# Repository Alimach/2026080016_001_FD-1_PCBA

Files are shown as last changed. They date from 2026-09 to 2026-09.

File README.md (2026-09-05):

# 2026080016_001_FD-1_PCBA

Проект печатной платы гитарной педали "First Distortion FD-1".

ID проекта: 2026080016.001

© Александр Алимов, 2026

---

## Лицензия

Данный проект распространяется под лицензией **Creative Commons CC-BY-NC 4.0**, 
согласно которой вы можете свободно делиться материалом и адаптировать его под 
свои нужды, при условии указания авторства и некоммерческого использования 
(подробнее см. файл LICENSE).

## Описание проекта

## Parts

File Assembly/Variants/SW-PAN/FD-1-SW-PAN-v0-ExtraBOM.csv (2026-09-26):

Name | Value | Qty | Unit | Описание | Type | MPN | Manufacturer | Chipdip_link | Diy-tubes_link | Diy-tubes_alt_link
Плата печатная 2026080016.001 FD-1 v0 |  | 1 | pcs |  | Detail | PCB-2026080016-001-FD-1-v0
Лепесток 1-2-13-36 |  | 1 | pcs | Для подключения GND к корпусу | Other
Провод МГШВ-0,2 кв.мм (AWG24), белый | 0,2 кв.мм (AWG24), белый | 100 | mm |  | Material
Провод МГШВ-0,2 кв.мм (AWG24), красный | 0,2 кв.мм (AWG24), красный | 50 | mm |  | Material
Провод МГШВ-0,2 кв.мм (AWG24), черный | 0,2 кв.мм (AWG24), черный | 100 | mm |  | Material
Трубка ПВХ Ø 1 мм | Ø 1 мм |  | mm |  | Material
Вилка штыревая PLH-5 | PLH-5 | 1 | pcs |  | Other

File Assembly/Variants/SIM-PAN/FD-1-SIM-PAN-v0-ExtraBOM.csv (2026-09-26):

Name | Value | Qty | Описание | MPN | Manufacturer | Chipdip_link | Diy-tubes_link | Diy-tubes_alt_link
Плата печатная 2026080016.001 FD-1 v0 |  | 1 |  | PCB-2026080016-001-FD-1-v0
Провод МГШВ-0.2 кв.мм (AWG24) | 0.2 кв.мм (AWG24)
Лепесток 1-2-13-36 |  | 1 | Для подключения GND к корпусу

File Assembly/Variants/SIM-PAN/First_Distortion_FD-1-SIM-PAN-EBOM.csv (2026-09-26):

Reference | Name | Value | Tolerance | Voltage | Power | Temperature | Material | Package | PinPitch | Qty | Описание | MPN | Manufacturer | Chipdip_link | Diy-tubes_link | Diy-tubes_alt_link
C1,C9 | Конденсатор THT металлоплёночный | 1n | 20% | 63V |  |  | MKT | C-THT-RECT-L7-W2.5-H6.5 | 5 | 2 |  | B32529C0102 | Epcos | https://www.chipdip.ru/product/b32529c0102j000-0.001-mkf-40vac-63vdc-shag-5mm-5-tdk-epcos-9000635053 | https://diy-tubes.ru/index.php?route=product/product&path=25_32&product_id=912 | https://diy-tubes.ru/index.php?route=product/product&path=25_32&product_id=560
C2 | Конденсатор THT металлоплёночный | 10n | 20% | 63V |  |  | MKT | C-THT-RECT-L7-W2.5-H6.5 | 5 | 1 |  | B32529C0103 | Epcos | https://www.chipdip.ru/product/b32529c0103j000-tdk-8008394032 | https://diy-tubes.ru/index.php?route=product/product&path=25_32&product_id=912 | https://diy-tubes.ru/index.php?route=product/product&path=25_32&product_id=560
C3 | Конденсатор THT металлоплёночный | 47n | 20% | 63V |  |  | MKT | C-THT-RECT-L7-W2.5-H6.5 | 5 | 1 |  | B32529C0473 | Epcos | https://www.chipdip.ru/product/mkt-film-capacitor-47-nf-10-63-v-dc-pet-5-mm-tdk-8026536943 | https://diy-tubes.ru/index.php?route=product/product&path=25_32&product_id=912 | https://diy-tubes.ru/index.php?route=product/product&path=25_32&product_id=560
C4 | Конденсатор THT электролитический алюминиевый | 100u | 20% | 16V |  | 85 °C | AL-EL | C-THT-RADIAL-D5-H11 | 2.5 | 1 |  | JRB1C101M02000500110 | JB | https://www.chipdip.ru/product/100mkf-16v-105-c-20-5x11mm-p-2mm-jb-capacitors-9000565888
C5 | Конденсатор THT керамический | 10p | 5% | 50V |  |  | NP0 | C-THT-RECT-L5-W2.5-H5 | 5 | 1 |  | JYM1H100JBN | JB | https://www.chipdip.ru/product/k10-17b-10pf-npo-5-0805-jym1h100jbn010000b-jb-capacitors-9001397195 |  | https://diy-tubes.ru/index.php?route=product/product&path=25_32&product_id=937
C6 | Конденсатор THT электролитический танталовый | 1u | 10% | 50V |  |  | TA-EL | C-THT-RADIAL-D5-H11 | 2.5 | 1 | Танталовый, ниобиевый | TC-1/50 | SR Passives | https://www.chipdip.ru/product/tc-1-50-kondensator-tantalovyy-1mkf-50v-tht-20-sr-passives-8017379192
C7 | Конденсатор THT электролитический алюминиевый | 1u | 20% | 50V |  | 85 °C | AL-EL | C-THT-RADIAL-D5-H11 | 2.5 | 1 |  | JRB1H010M02000500110 | JB | https://www.chipdip.ru/product/1mkf-50v-105-c-20-5x11mm-p-2mm-jb-capacitors-9000565817 |  | https://diy-tubes.ru/index.php?route=product/product&path=25_32&product_id=330
C8 | Конденсатор THT керамический | 100n | 20% | 50V |  |  | X7R | C-THT-RECT-L5-W2.5-H5 | 5 | 1 | Керамический дисковый или многослойный, диэлектрик X5R, X7R, в крайнем случае Y5V | JYM1H102KBX | JB | https://www.chipdip.ru/product/k10-17b-1000pf-x7r-10-0805-jym1h102kbx010000b-jb-capacitors-9001397221 |  | https://diy-tubes.ru/index.php?route=product/product&path=25_32&product_id=179
DA1 | Микросхема uA741 | uA741 |  |  |  |  |  | DIP8 |  | 1 | Любой аналог: КР140УД7, К140УД7, MAA741 и т.д. Можно в металлическом круглом корпусе TO-99-8 | UA741CP | TI | https://www.chipdip.ru/product/ua741cp-universalnyy-odnokanalnyy-texas-instruments-9000375054 |  | https://diy-tubes.ru/index.php?route=product/product&path=25_61&product_id=698
HL1 | Светодиод THT, Ø 3 мм, красный | RED |  |  |  |  |  | LED-THT-D3 |  | 1 | Любой выводной светодиод 3 мм | GNL-3012HD | G-NOR | https://www.chipdip.ru/product/gnl-3012hd-svetodiod-krasnyy-60-d-3mm-5-10mkd-700nm-g-nor-9000422968 |  | https://diy-tubes.ru/index.php?route=product/product&path=25_77&product_id=398
R1,R5,R6,R7,R8 | Резистор THT металлоплёночный | 1M | 5% |  | 0.125W |  |  | DIN0207 |  | 5 |  | KLS6-MF-1/4W-1MR-J | KLS | https://www.chipdip.ru/product/mfr-25ftf52-1m-0.25vt-1mom-1-rezistor-resurs-9002018565 |  | https://diy-tubes.ru/index.php?route=product/product&path=25_30&product_id=143
R2,R9 | Резистор THT металлоплёночный | 4k7 | 5% |  | 0.125W |  |  | DIN0207 |  | 2 |  | KLS6-MF-1/4W-4K7R-J | KLS | https://www.chipdip.ru/product/mf-25-s2-23-0.25vt-4.7-kom-1-rezistor-metalloplenochnyy-1849 |  | https://diy-tubes.ru/index.php?route=product/product&path=25_30&product_id=143
R3 | Резистор THT металлоплёночный | 10R | 5% |  | 0.125W |  |  | DIN0207 |  | 1 | Допускается углеродистый | KLS6-MF-1/4W-10R-J | KLS | https://www.chipdip.ru/product/mfr-25ftf52-10r-0.25vt-10om-1-rezistor-resurs-9002018531
R4,R10 | Резистор THT металлоплёночный | 10k | 5% |  | 0.125W |  |  | DIN0207 |  | 2 |  | KLS6-MF-1/4W-10KR-J | KLS | https://www.chipdip.ru/product/mfr-25ftf52-10k-0.25vt-10kom-1-rezistor-resurs-9002018555
R11 | Резистор SMD металлоплёночный | 0 |  |  | 0.125W |  |  | SMD0805 |  | 1 |  | CR-05JL7----0R | VIKING | https://www.chipdip.ru/product/cr-05fl7-0r-rezistor-tolstoplenochnyy-125mvt-1-0ohm-viking-8020205931
RP1 | Потенциометр RV16AF-10-15K | C500k |  |  |  |  |  | RV16AF-10 |  | 1 | Обратнологарифмический (C) | RV16AF-10-15K-C500k | Alpha |  | https://diy-tubes.ru/index.php?route=product/product&path=25_63&product_id=414 | https://diy-tubes.ru/index.php?route=product/product&path=25_63&product_id=587
RP2 | Потенциометр RV16AF-10-15K | A50k |  |  |  |  |  | RV16AF-10 |  | 1 | Логарифмический (A) | RV16AF-10-15K-A50k | Alpha |  | https://diy-tubes.ru/index.php?route=product/product&path=25_63&product_id=170 | https://diy-tubes.ru/index.php?route=product/product&path=25_63&product_id=587
S1 | Переключатель ножной 3PDT SF17010F-0302 | SF17010F-0302 |  |  |  |  |  | SF17010F-0302 |  | 1 | Классический 3PDT под пайку провода | SF17010F-0302 | Alpha |  |  | https://diy-tubes.ru/index.php?route=product/product&path=25_60&product_id=148
VD1 | Диод кремниевый 1N4001 | 1N4001 |  | 25V |  |  | Si | DO-41 |  | 1 | Любой диод DO-41 средней мощности, V > 25 В | 1N4001 | DC Components | https://www.chipdip.ru/product/1n4001-diod-vypryamitelnyy-1a-50v-do-41-dc-components-9000820620 | https://diy-tubes.ru/index.php?route=product/product&path=25_64&product_id=889
VD2,VD3 | Диод германиевый 1N34A (Д9) | 1N34A (Д9) |  |  |  |  | Ge | DO-35 |  | 2 | Любой германиевый маломощный диод (макс. размер DO-41): Д9, Д310 и т.д. | Д9 |  | https://www.chipdip.ru/product/d9b-diod-vypryamitelnyy-maloy-moschnosti-germanievyy-48370 | https://diy-tubes.ru/index.php?route=product/product&path=25_64&product_id=617
X2 | Гнездо питания KLS1-DC-022B-2.0 | KLS1-DC-022B-2.0 |  |  |  |  |  | KLS1-DC-022B-2.0 |  | 1 | 2,0х5,5 мм, на панель, крепёжное отверстие Ø 11 мм, гайка снизу, под пайку провода | KLS1-DC-022B-2.0 | KLS |  | https://diy-tubes.ru/index.php?route=product/product&path=25_81&product_id=420
X3 | Разъём для батареи типа "Крона" боковой |  |  |  |  |  |  |  |  | 1 |  |  |  |  | https://diy-tubes.ru/index.php?route=product/product&path=25_81&product_id=295
XS1,XS2 | Гнездо Jack 6,3 мм TRS NMJ6HCD2 | NMJ6HCD2 |  |  |  |  |  |  |  | 2 |  | NMJ6HCD2 | Neutrik |  | https://diy-tubes.ru/index.php?route=product/product&path=25_65&product_id=168 | https://diy-tubes.ru/index.php?route=product/product&path=25_65&product_id=228

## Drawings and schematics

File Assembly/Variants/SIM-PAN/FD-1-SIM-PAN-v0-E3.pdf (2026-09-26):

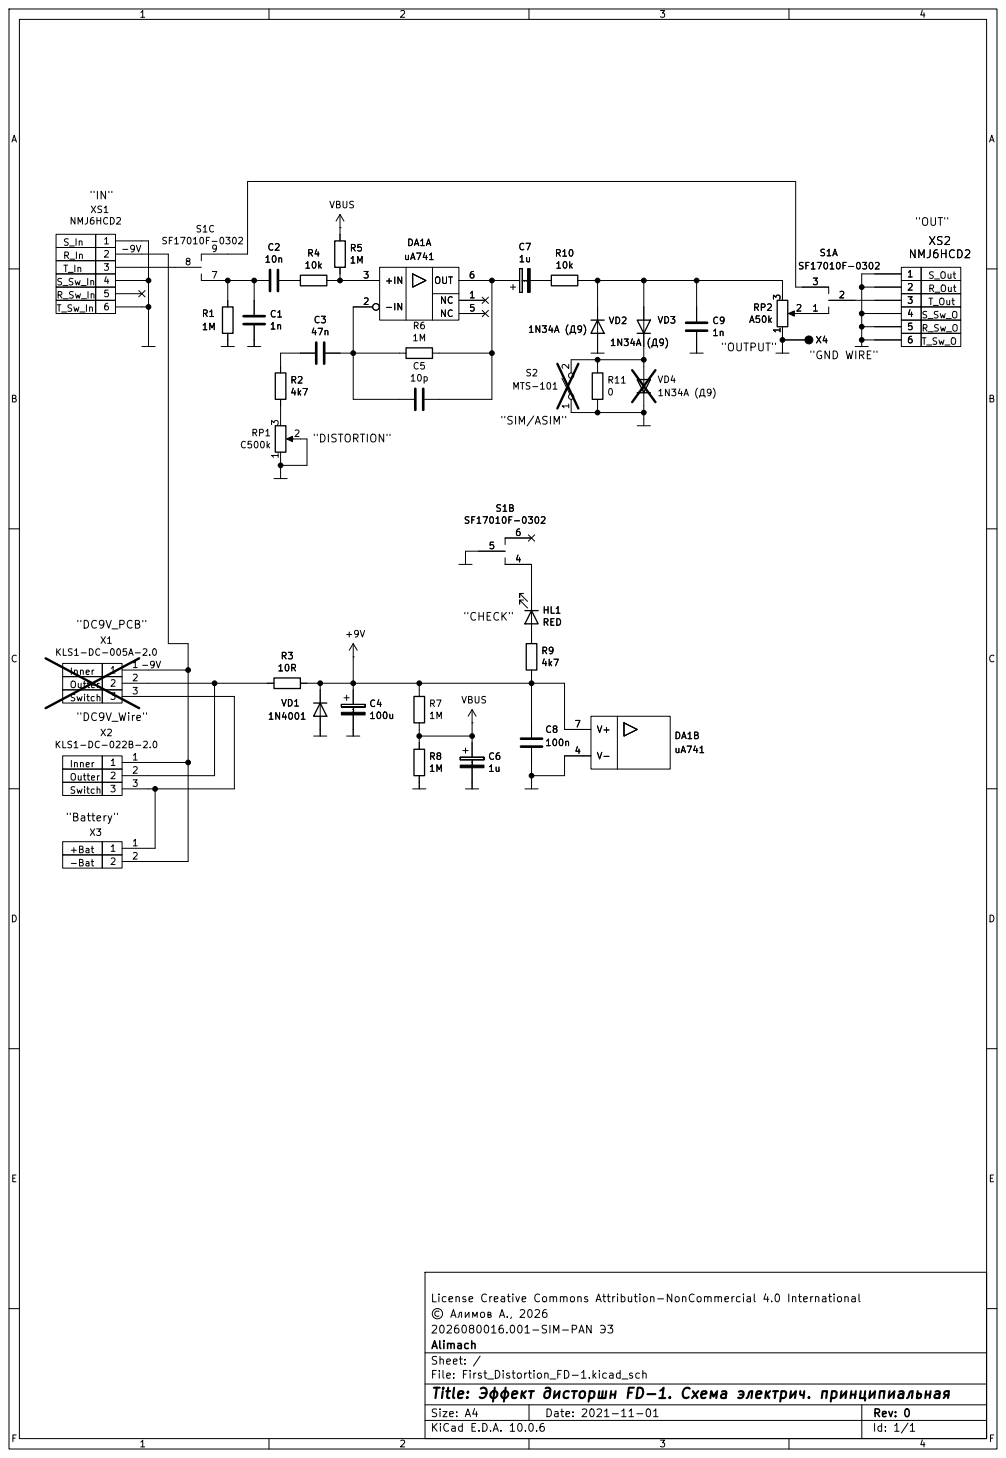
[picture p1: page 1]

2 2
3 3
4 4

3 | 4k7 C6

License Creative Commons Attribution-NonCommercial 4.0 International
© Алимов А., 2026
2026080016.001-SIM-PAN Э3
Alimach
Sheet: /
File: First_Distortion_FD-1.kicad_sch
Title: Эффект дисторшн FD-1. Схема электрич. принципиальная

Size: A4 | Rev: 0 | F Date: 2021-11-01
KiCad E.D.A. 10.0.6 | Id: 1/1

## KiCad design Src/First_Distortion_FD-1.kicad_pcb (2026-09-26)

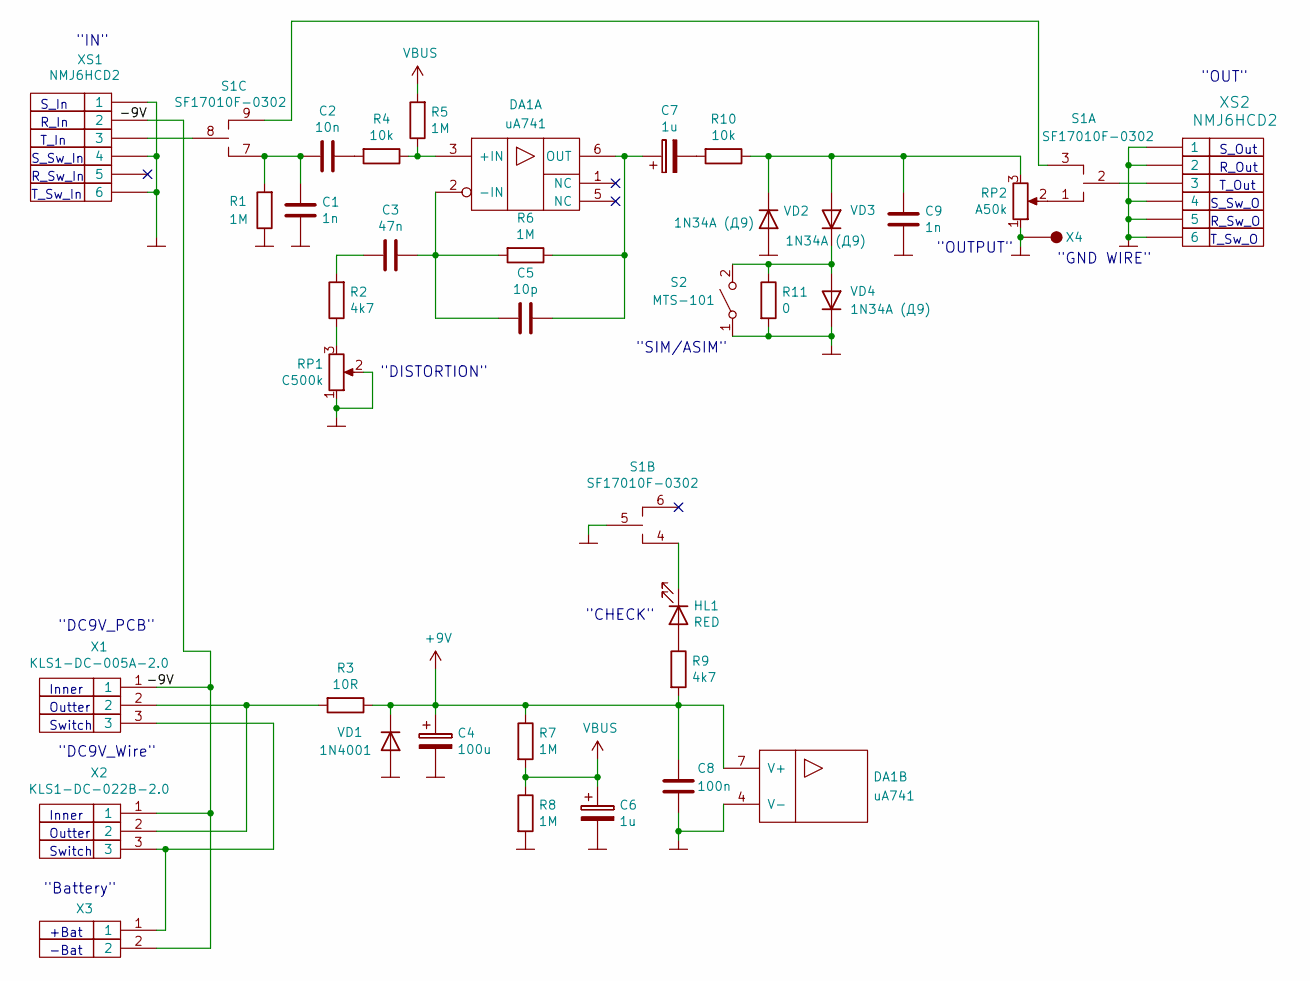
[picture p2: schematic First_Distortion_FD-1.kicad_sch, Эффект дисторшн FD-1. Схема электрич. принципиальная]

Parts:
C1, C9: 1n; C_Rect_L7.0mm_W2.5mm_P5.00mm; Tolerance 20%; Voltage 63V; MPN B32529C0102
C2: 10n; C_Rect_L7.0mm_W2.5mm_P5.00mm; Tolerance 20%; Voltage 63V; MPN B32529C0103
C3: 47n; C_Rect_L7.0mm_W2.5mm_P5.00mm; Tolerance 20%; Voltage 63V; MPN B32529C0473
C4: 100u; CP_Radial_D5.0mm_P2.50mm; Tolerance 20%; Voltage 16V; MPN JRB1C101M02000500110
C5: 10p; C_Disc_D5.0mm_W2.5mm_P5.00mm; Tolerance 5%; Voltage 50V; MPN JYM1H100JBN
C6: 1u; CP_Radial_D5.0mm_P2.50mm; Tolerance 10%; Voltage 50V; MPN TC-1/50
C7: 1u; CP_Radial_D5.0mm_P2.50mm; Tolerance 20%; Voltage 50V; MPN JRB1H010M02000500110
C8: 100n; C_Disc_D5.0mm_W2.5mm_P5.00mm; Tolerance 20%; Voltage 50V; MPN JYM1H102KBX
DA1: uA741; DIP-8_W7.62mm_LongPads; MPN UA741CP
HL1: RED; LED_D3.0mm; MPN GNL-3012HD
R1, R5, R6, R7, R8: 1M; R_Axial_DIN0207_L6.3mm_D2.5mm_P7.62mm_Horizontal; Tolerance 5%; MPN KLS6-MF-1/4W-1MR-J
R2, R9: 4k7; R_Axial_DIN0207_L6.3mm_D2.5mm_P7.62mm_Horizontal; Tolerance 5%; MPN KLS6-MF-1/4W-4K7R-J
R3: 10R; R_Axial_DIN0207_L6.3mm_D2.5mm_P7.62mm_Horizontal; Tolerance 5%; MPN KLS6-MF-1/4W-10R-J
R4, R10: 10k; R_Axial_DIN0207_L6.3mm_D2.5mm_P7.62mm_Horizontal; Tolerance 5%; MPN KLS6-MF-1/4W-10KR-J
R11: 0; R_0805_HandSoldering; MPN CR-05JL7----0R
RP1: C500k; Alpha; MPN RV16AF-10-15K-C500k
RP2: A50k; Alpha; MPN RV16AF-10-15K-A50k
S1: SF17010F-0302; 3PDT_Standart_Wire; MPN SF17010F-0302
S2: MTS-101; Conn_x2; MPN MTS-101
VD1: 1N4001; D_DO-41_SOD81_P7.62mm_Horizontal; Voltage 25V; MPN 1N4001
VD2, VD3, VD4: 1N34A (Д9); D_DO-41_SOD81_P7.62mm_Horizontal; MPN Д9
X1: KLS1-DC-005A-2.0; BARREL_JACK; MPN KLS1-DC-005A-2.0
X2: KLS1-DC-022B-2.0; Fan_Pin_Header_Straight_1x03; MPN KLS1-DC-022B-2.0
X3: Conn_x2
X4: SolderWirePad_single_1mmDrill
XS1, XS2: NMJ6HCD2; Jack_6.3_Stereo_2; MPN NMJ6HCD2

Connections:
+9V: C4.1, C8.1, DA1.7 (V+), R3.1, R7.1, R9.2, VD1.1 (K)
/-9V: X1.1, X2.1, X3.2, XS1.2
GND_AAV: C1.1, C4.2, C6.2, C8.2, C9.1, DA1.4 (V-), R1.1, R8.2, R11.2, RP1.1, RP1.2, RP2.1, S1.5, S2.1 (A), VD1.2 (A), VD2.2 (A), VD4.1 (K), X4.1 (~_1), XS1.1, XS1.4, XS1.6, XS2.1, XS2.2, XS2.4, XS2.5, XS2.6
unnamed: C1.2, C2.2, R1.2, S1.7
unnamed: C2.1, R4.2
unnamed: C3.2, R2.2
unnamed: C7.2, R10.2
unnamed: DA1.3 (+IN), R4.1, R5.1
unnamed: C3.1, C5.2, DA1.2 (-IN), R6.2
unnamed: C5.1, C7.1, DA1.6 (OUT), R6.1
unnamed: HL1.2 (A), R9.1
unnamed: HL1.1 (K), S1.4
unnamed: R2.1, RP1.3
unnamed: R3.2, X1.2, X2.2
unnamed: RP2.2, S1.1
unnamed: S1.2, XS2.3
unnamed: S1.3, S1.9
unnamed: S1.8, XS1.3
unnamed: R11.1, S2.2 (B), VD3.1 (K), VD4.2 (A)
unnamed: C9.2, R10.1, RP2.3, VD2.1 (K), VD3.2 (A)
unnamed: X1.3, X2.3, X3.1
VBUS: C6.1, R5.2, R7.2, R8.1

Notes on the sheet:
Outter
R_Sw_O
"DC9V_Wire"
S_Sw_O
T_Sw_In
"IN"
R_In
T_Out
+Bat
"Battery"
T_Sw_O
-Bat
Inner
T_In
"DC9V_PCB"
"DISTORTION"
S_In
S_Sw_In
Switch
"GND WIRE"
"CHECK"
"OUTPUT"
"OUT"
R_Sw_In
R_Out
"SIM/ASIM"
S_Out

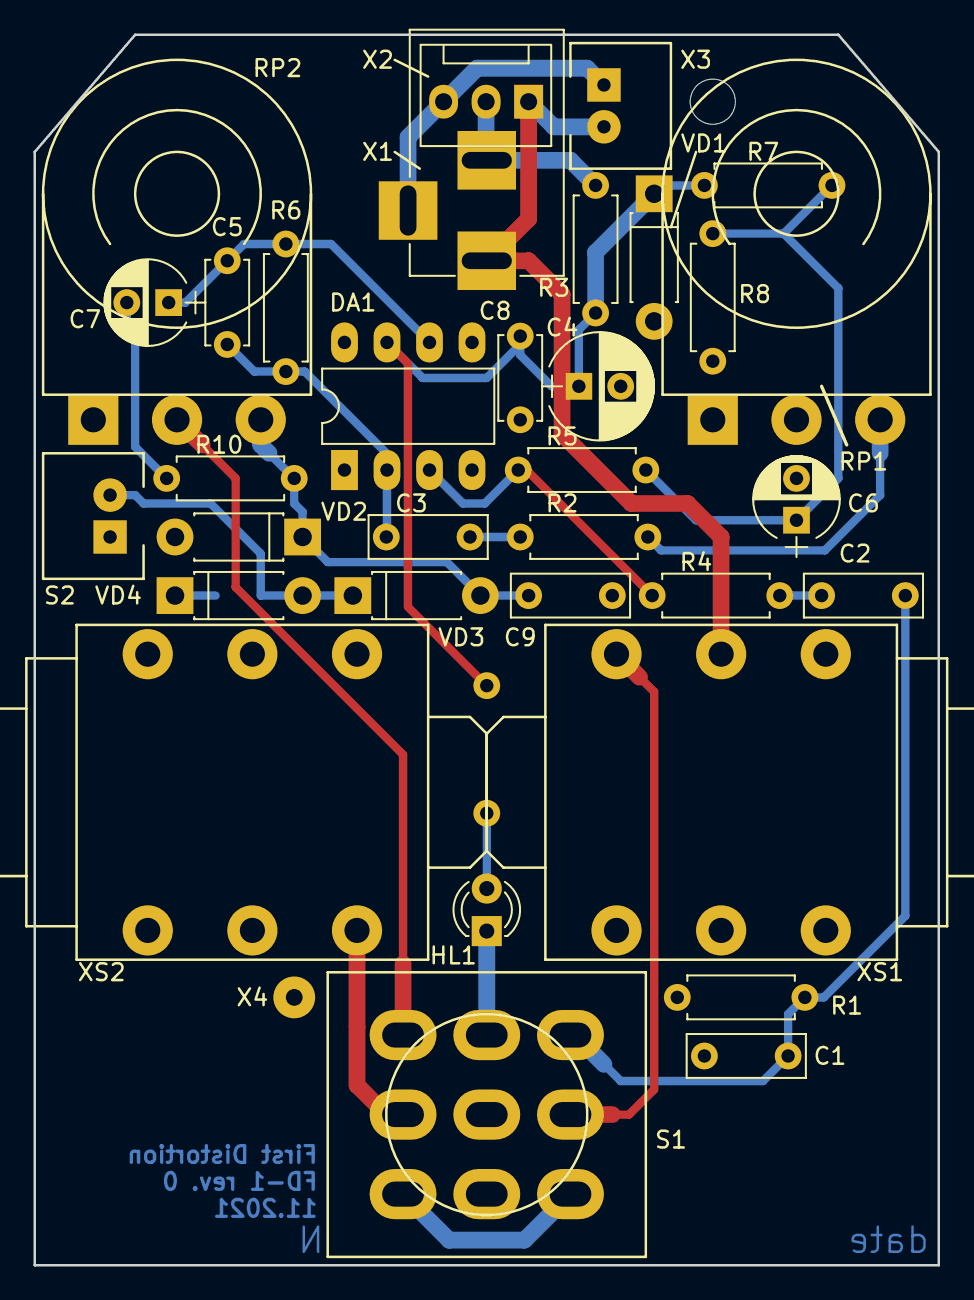
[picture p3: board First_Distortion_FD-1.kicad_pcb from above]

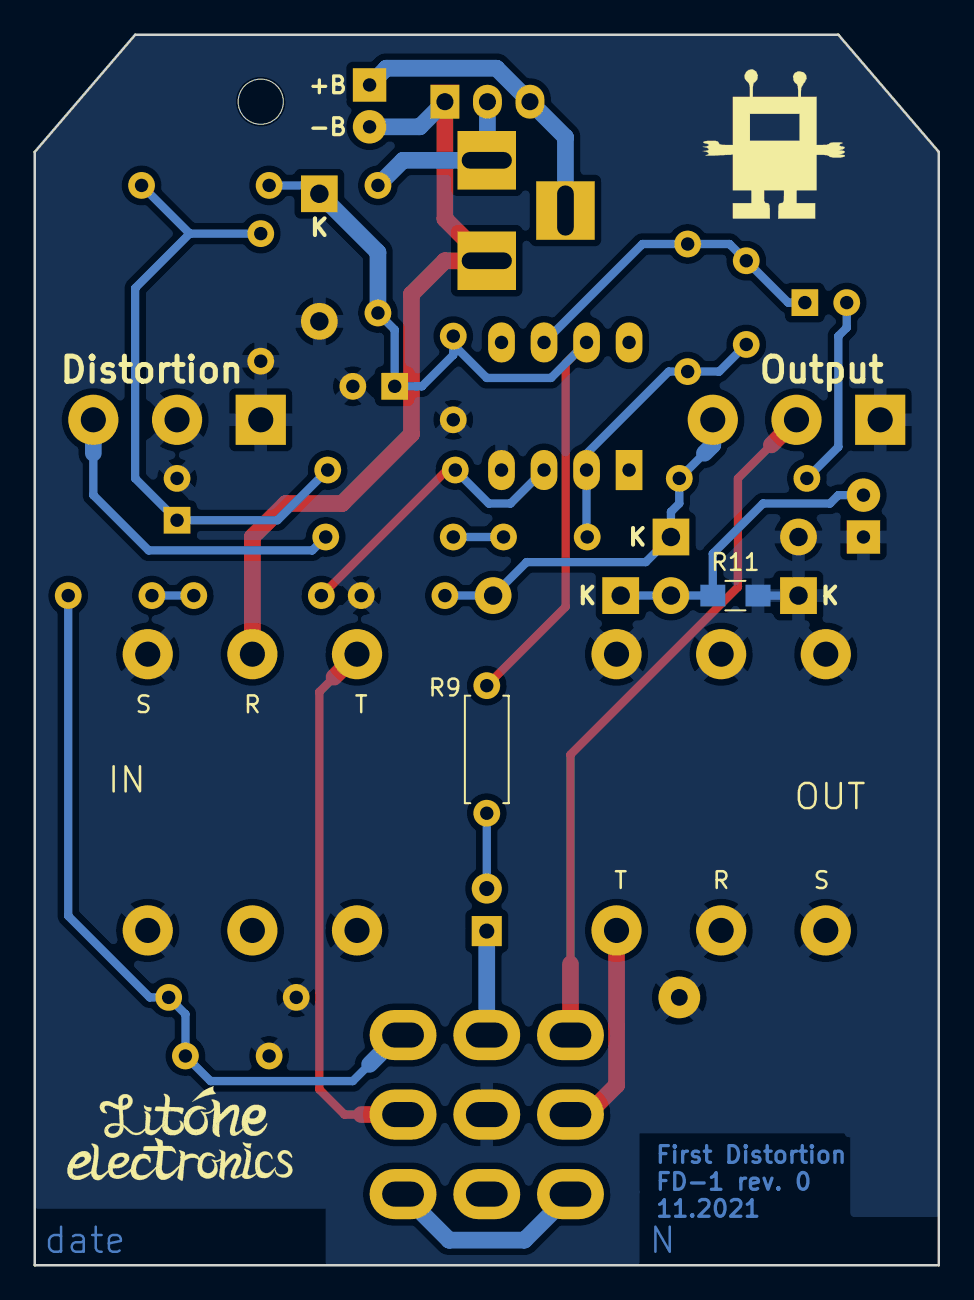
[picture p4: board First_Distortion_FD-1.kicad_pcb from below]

Board: 2 copper layers, 54.0 x 73.5 mm, 36 parts (2 on the bottom side), 22 nets.

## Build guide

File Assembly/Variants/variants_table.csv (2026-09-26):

variant | description
SIM-PCB | SIM - только симметричное ограничение. PCB - гнездо питания на плату
SIM-PAN | SIM - только симметричное ограничение. PAN - гнездо питания на панель
SW-PCB | SW - переключатель симметричное/несимметричное ограничение. PCB - гнездо питания на плату
SW-PAN | SW - переключатель симметричное/несимметричное ограничение. PAN - гнездо питания на панель

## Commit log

2026-09-05 Реформирование структуры, добавление лицензии
    * Переопределена структура проекта согласно соглашению по разработке АО
    * Добавлена лицензия CC BY-NC 4.0
    [First_Distortion_FD-1.kicad_pcb, First_Distortion_FD-1.sch]
2026-09-05 Оформление рамки схемы
    [First_Distortion_FD-1.sch]
2026-09-05 Добавление 3Д-моделей на плату
    [First_Distortion_FD-1.kicad_pcb]
2026-09-06 Первая итерация формирования BOM, 3D модели
    [First_Distortion_FD-1.kicad_pcb, First_Distortion_FD-1.sch]
2026-09-06 Переход на KiCAD 10, формирование вариантов
    * Запустил проект в KiCAD 10
    * Добавил варианты исполнения
    [First_Distortion_FD-1.kicad_pcb, First_Distortion_FD-1.kicad_sch]
2026-09-16 pcba: Предварительное приведение в порядок BOM
    [First_Distortion_FD-1.kicad_sch]
2026-09-18 Продолжение наполнения BOM для разных исполнений
    [First_Distortion_FD-1.kicad_sch]
2026-09-19 Заменил пути к 3D на относительные
    [First_Distortion_FD-1.kicad_pcb]
2026-09-19 Вывод BOM и перечня элементов для всех вариантов
    * _EBOM.csv - спецификация, сгенерированная KiCAD
    * _PE3.csv - перечень элементов (все элементы по порядку,
    без группировки), сгенерированный KiCAD
    * _MBOM.csv - производственная спецификация
    (EBOM + доп. детали и материалы для сборки платы)
    [2026080016.001-FD-1-PCBA-SIM-PAN-v0-EBOM.csv, 2026080016.001-FD-1-PCBA-SIM-PAN-v0-MBOM.csv, 2026080016.001-FD-1-PCBA-SIM-PAN-v0-PE3.csv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]
2026-09-19 Вывод схем всех вариантов
    [First_Distortion_FD-1.kicad_sch]
2026-09-19 Подготовка черновика СБ
    [First_Distortion_FD-1.kicad_pcb, First_Distortion_FD-1.kicad_sch]
2026-09-26 Исправление BOM и вывода схемы
    * Поправил логику работы с BOM
    * Исправил содержимое BOM
    * Изменил рамку схемы на стандартную
    * Добавил необходимое описание для рамки схемы
    [2026080016.001-FD-1-PCBA-SIM-PAN-v0-EBOM.csv, 2026080016.001-FD-1-PCBA-SIM-PAN-v0-MBOM.csv, 2026080016.001-FD-1-PCBA-SIM-PAN-v0-PE3.csv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]
2026-09-26 Начало работы над СБ, дополнение ExtraBOM (SW-PAN)
    [FD-1-SW-PAN-v0-ExtraBOM.csv, First_Distortion_FD-1.kicad_pcb]
2026-09-26 Добавление EBOM всех вариантов в репозиторий
    [First_Distortion_FD-1-SIM-PAN-EBOM.csv, First_Distortion_FD-1-SIM-PCB-EBOM.csv, First_Distortion_FD-1-SW-PAN-EBOM.csv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]
